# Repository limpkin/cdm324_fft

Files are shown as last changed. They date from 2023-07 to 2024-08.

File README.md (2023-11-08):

# CDM324 v2 FFT Project
This repository contains the source files created for the making of the CDM324 project described on <a href="https://www.limpkin.fr/index.php?post/2022/03/31/CDM324-Doppler-Motion-Sensor-Backpack%2C-now-with-FFTs%21">limpkin.fr</a>  
The assembly may be purchased here: <a href="https://www.tindie.com/products/stephanelec/cdm324-doppler-speed-sensor/">US shop</a> / <a href="https://lectronz.com/products/cdm324-doppler-speed-sensor">EU shop</a>   
<p align="center">
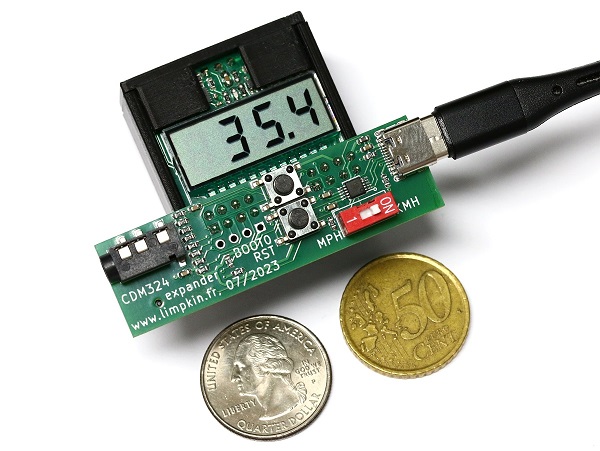
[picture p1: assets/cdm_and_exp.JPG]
CDM324
  
</p>

## Repository Structure
- <b>datasheets</b>: main components datasheets
- <b>fw</b>: firmware source files, used in STM32CubeIDE
- <b>kicad</b>: kicad source files for the "backpack" (cdm324_v2) and the "expansion board" (cdm324_exp)
- <b>scripts</b>: python source files for the tools that are used together with the expansion board

## Quick Interfacing Guide (to be completed)
<p align="center">
  CDM324
</p>

### Unit change to km/h  
To change the speed readout to km/h, connect the "PA1/KMH" pad to the "GND" pad in the above diagram.  

### UART connection  
**The UART connection is 3V3 and NOT 5V.**  
To connect the device to an external platform through UART, please use the MCU UART RX/TX pins shown above.   
The baud rate is **1Mbit/s**, speed **can be queried** by **sending the 'k'** character for km/h or the 'm' character for mph.  
**In case of doubt about the UART connection, reboot the device**: it should output "CDM324 fw....".  
**Make sure your host device can handle 1MBit/s**. If that's not the case, head to the [release section](https://github.com/limpkin/cdm324_fft/releases) to download firmware with different UART baud rates.  
Finally, if you still have doubts about the UART connection, you may connect one of your host platform GPIO to the nRESET pin and reset the CDM324 device at your host platform boot.  

## Reflashing the Device

In the unlikely case you want to reflash your device with another firmware, you may either use the [GUI present in this repository](https://github.com/limpkin/cdm324_fft/tree/main/scripts) or the [stm32loader python module](https://pypi.org/project/stm32loader/) directly :  

> pip install stm32loader
> 
... then with the expansion board connected to the device (**as it uses RTS/CTS signals to control the MCU nRESET and BOOT0 pins**):  

> stm32loader -b 115200 -p  com_port -e -w -v -s -f F3 updatefile.bin

If you don't have the companion expansion board, you may use [STM32 Flash loader](https://www.st.com/en/development-tools/flasher-stm32.html) after performing the following toggling sequence:  
- tie nRESET to GND  
- bring BOOT0 to 3V3_OUT  
- release nRESET  
- releae BOOT0  

## Sample Arduino code to fetch speed from device

```c
#define RESET_PIN 2

void issue_cdm324_reset()
{  
  bool string_received = false;
  char receive_buffer[50];
  int index = 0;

  // 20ms reset
  pinMode(RESET_PIN, OUTPUT);
  delay(20);
  pinMode(RESET_PIN, INPUT);

  // get string
  while (string_received == false)
  {
    if (Serial1.available() > 0)
    {
      char bla = Serial1.read();
      receive_buffer[index++] = bla;
      if (bla == '\n')
        string_received = true;
    }
  }
  receive_buffer[index] = 0;

  Serial.println("Received from the CDM324:");
  Serial.println(receive_buffer);
}

void setup() 
{
  // Local console
  Serial.begin(115200);
  Serial.println("Hello there!");

  // To the CDM324
  Serial1.begin(57600);

  // Reset CDM324
  pinMode(RESET_PIN, INPUT);
  digitalWrite(RESET_PIN, LOW);
  issue_cdm324_reset();
}

float get_speed(bool kmh)
{
  if (kmh == true)
  {
    // Query km/h * 10
    Serial1.print('k');
  }
  else
  {
    // Query mph * 10
    Serial1.print('m');
  }  
  while(Serial1.available() == 0);
  float speed = Serial1.parseFloat();
  return (speed / 10);
}

void loop()
{
  Serial.println(get_speed(false));
  delay(500);
}
```

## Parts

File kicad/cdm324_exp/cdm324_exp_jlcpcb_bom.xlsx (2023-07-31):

Designator | Comment | Footprint | JLCPCB Part #
C1, C2, C3, C4, C5 | 1uF | Capacitor_SMD:C_0603_1608Metric | C1592
FB1 | FerriteBead | Inductor_SMD:L_0603_1608Metric | C14709
J1, J2 | Conn_02x04_Odd_Even | Connector_PinSocket_2.54mm:PinSocket_2x04_P2.54mm_Vertical | C2685133
J3 | USB_C_Receptacle_USB2.0 | Connector_USB:USB_C_Receptacle_G-Switch_GT-USB-7010ASV | C2988369
J5 | Micro_SD_Card_Det1 | lib:XKTF-015-N | C381082
J7 | AudioJack4 | Connector_Audio:Jack_3.5mm_PJ320D_Horizontal | C431535
R1, R4, R5, R6, R7 | 1k | Resistor_SMD:R_0603_1608Metric | C22548
R2, R3 | 5.1k | Resistor_SMD:R_0603_1608Metric | C105580
R8, R9, R10, R11, R12, R13 | 49k9 | Resistor_SMD:R_0603_1608Metric | C114624
SW1, SW2 | SW_Push | Button_Switch_SMD:SW_Push_1P1T_NO_6x6mm_H9.5mm | C255812
SW3 | SW_DIP_x01 | Button_Switch_THT:SW_DIP_SPSTx01_Slide_9.78x4.72mm_W7.62mm_P2.54mm | C126888
U1 | CH340X | Package_SO:MSOP-10_3x3mm_P0.5mm | C3035748

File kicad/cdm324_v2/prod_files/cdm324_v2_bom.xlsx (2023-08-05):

Item # | Qty | Designator | Value | Manufacturer | Manufacturer Part Number | Alternative LCSC part number | Package/Footprint | Digikey Link
1 | 6 | C1, C3, C5, C10, C11, C13 | 22uF | Samsung Electro-Mechanics | CL21A226MOCLRNC | C602037 | 0805 | https://www.digikey.com/product-detail/en/samsung-electro-mechanics/CL21A226MOCLRNC/1276-6780-1-ND/5961639
2 | 1 | C4 | 27pF | YAGEO | CC0603JRNPO9BN270 | C107045 | 0603 | https://www.digikey.com/en/products/detail/yageo/CC0603JRNPO9BN270/302797
3 | 9 | C2, C6, C7, C8, C12, C14, C15, C16, C18 | 470nF | TDK Corporation | C1005X5R1E474K050BB | C92361 | 0402 | https://www.digikey.com/en/products/detail/tdk-corporation/C1005X5R1E474K050BB/2792240
4 | 1 | C9 | 2.2uF | Murata Electronics | GRM188R71A225KE15D | C1607 | 0603 | https://www.digikey.com/en/products/detail/murata-electronics/GRM188R71A225KE15D/1033256
5 | 1 | FB1 | Ferrite_Bead | Laird-Signal Integrity Products | HZ0805D102R-10 | C44838 | 0805 | http://www.digikey.com/product-detail/en/HZ0805D102R-10/240-2397-1-ND/806757
6 | 1 | J2 | Conn_01x03_Female | Sullins Connector Solutions | PPPC031LFBN-RC | C146243 |  | http://www.digikey.com/product-detail/en/sullins-connector-solutions/PPPC031LFBN-RC/S7036-ND/810175
7 | 2 | J4, J5 | Conn_02x04_Odd_Even | Sullins Connector Solutions | PPPC042LFBN-RC | C92271 |  | https://www.digikey.com/en/products/detail/sullins-connector-solutions/PPPC042LFBN-RC/810244
8 | 5 | R1, R4, R8, R9, R10 | 4k7 | YAGEO | RC0603FR-074K7L | C99782 | 0603 | https://www.digikey.com/en/products/detail/yageo/RC0603FR-074K7L/727212
9 | 2 | R2, R7 | 75 | YAGEO | RC0402JR-0775RL | C137841 | 0402 | https://www.digikey.com/en/products/detail/yageo/RC0402JR-0775RL/726505
10 | 2 | R5, R6 | 130k | Panasonic Electronic Components | ERJ-3EKF1303V | C163432 | 0603 | https://www.digikey.com/product-detail/en/panasonic-electronic-components/ERJ-3EKF1303V/P130KHCT-ND/198154
11 | 1 | U1 | LMP7731 | Texas Instruments | LMP7731MF/NOPB | C202252 |  | https://www.digikey.ch/en/products/detail/texas-instruments/LMP7731MF-NOPB/1836050
12 | 1 | U3 | MAX9814 | Analog Devices Inc./Maxim Integrated | MAX9814ETD+T | C41714 |  | https://www.digikey.com/en/products/detail/analog-devices-inc-maxim-integrated/MAX9814ETD-T/1703775
13 | 1 | U4 | NCP163ASN330T1G | onsemi | NCP163ASN330T1G | C603656 |  | https://www.digikey.com/product-detail/en/on-semiconductor/NCP163ASN330T1G/NCP163ASN330T1GOSCT-ND/10233513
14 | 1 | U5 | STM32F301K8Ux | STMicroelectronics | STM32F301K8U6 | C111684 |  | https://www.digikey.com/product-detail/en/stmicroelectronics/STM32F301K8U6/497-17411-ND/5051319
15 | 1 | U6 | PCA8561AHN/AY | NXP USA Inc. | PCA8561AHN/AY | C2653710 |  | https://www.digikey.ch/en/products/detail/nxp-usa-inc/PCA8561AHN-AY/5170024
16 | 1 | U2 | 12PIN TN Positive 4-Digits |  |  |  |  | https://www.aliexpress.com/item/1005003060952508.html
17 | 1 | R3 | 620k | YAGEO | RC0603FR-07620KL | C68737 | 0603

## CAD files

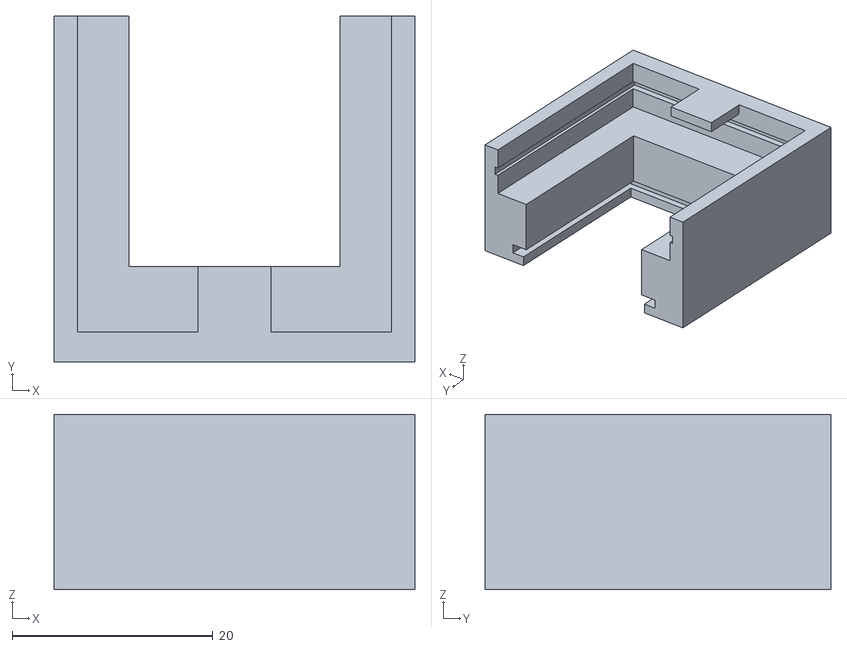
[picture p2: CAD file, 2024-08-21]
holder.stl
36.0 x 34.5 x 17.5

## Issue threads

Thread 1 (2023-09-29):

ffconf.h: No such file or directory

dogualpay, 2023-09-29:
Hi,

I purchased your device and I am trying to extract the .bin file from Cube IDE to upload it with UART connection. However your STM32 Cube IDE project doesn't build. Can you relate ? I couldn't find any proper solution for this issue by searching it on the net.

**Below my console output:**
```
In file included from ../Middlewares/Third_Party/FatFs/src/option/syscall.c:7:
../Middlewares/Third_Party/FatFs/src/option/../ff.h:27:10: fatal error: ffconf.h: No such file or directory
   27 | #include "ffconf.h"  /* FatFs configuration options */
      |          ^~~~~~~~~~
compilation terminated.
In file included from ../Middlewares/Third_Party/FatFs/src/ff_gen_drv.h:38,
                 from ../Middlewares/Third_Party/FatFs/src/diskio.c:40:
../Middlewares/Third_Party/FatFs/src/ff.h:27:10: fatal error: ffconf.h: No such file or directory
   27 | #include "ffconf.h"  /* FatFs configuration options */
      |          ^~~~~~~~~~
compilation terminated.
In file included from ../Middlewares/Third_Party/FatFs/src/ff.c:126:
../Middlewares/Third_Party/FatFs/src/ff.h:27:10: fatal error: ffconf.h: No such file or directory
   27 | #include "ffconf.h"  /* FatFs configuration options */
      |          ^~~~~~~~~~
compilation terminated.
make: *** [Middlewares/Third_Party/FatFs/src/option/subdir.mk:19: Middlewares/Third_Party/FatFs/src/option/syscall.o] Error 1
make: *** Waiting for unfinished jobs....
make: *** [Middlewares/Third_Party/FatFs/src/subdir.mk:25: Middlewares/Third_Party/FatFs/src/diskio.o] Error 1
make: *** [Middlewares/Third_Party/FatFs/src/subdir.mk:25: Middlewares/Third_Party/FatFs/src/ff.o] Error 1
In file included from ../Middlewares/Third_Party/FatFs/src/ff_gen_drv.h:38,
                 from ../Middlewares/Third_Party/FatFs/src/ff_gen_drv.c:29:
../Middlewares/Third_Party/FatFs/src/ff.h:27:10: fatal error: ffconf.h: No such file or directory
   27 | #include "ffconf.h"  /* FatFs configuration options */
      |          ^~~~~~~~~~
compilation terminated.
make: *** [Middlewares/Third_Party/FatFs/src/subdir.mk:25: Middlewares/Third_Party/FatFs/src/ff_gen_drv.o] Error 1
In file included from ../FATFS/App/fatfs.h:26,
                 from ../FATFS/App/fatfs.c:19:
../Middlewares/Third_Party/FatFs/src/ff.h:27:10: fatal error: ffconf.h: No such file or directory
   27 | #include "ffconf.h"  /* FatFs configuration options */
      |          ^~~~~~~~~~
compilation terminated.
make: *** [FATFS/App/subdir.mk:19: FATFS/App/fatfs.o] Error 1
"make -j16 all" terminated with exit code 2. Build might be incomplete.

11:10:57 Build Failed. 11 errors, 0 warnings. (took 962ms)```

limpkin, 2023-09-29:
thanks for flagging this! it seems gitignore was at fault: https://github.com/limpkin/cdm324_fft/commit/985b58a3213550a3e2f7e3fa087a3f2d90b99047

Closed 2023-09-29.

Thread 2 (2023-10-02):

Please share some further infos about this project

will-code-for-pizza, 2023-10-02:
Hi Limpkin.fr

Please provide us beginners with some more infos about the CMD324 FFT:

* Fritzing.org breadboard cabeling example (f.e. for Arduino UNO R4 Wifi)
* Detailed information about the capabilities of onboard connectors shown in [THIS PICTURE](https://www.limpkin.fr/public/cdm324_v2/exp_pinout.png)
* An example Arduino sketch file, that shows, how to print out measured speed on serial console with high accuracy

Many thanks so far.
Have a nice day.

limpkin, 2023-10-03:
Hello,
I'll try to get to it when I have the time.

will-code-for-pizza, 2023-10-03:
Sorry, please don't get me wrong, but you sell your excellent product online without any detailed documentation. It would be nice for every of your customers to follow your developement cabling and Arduino code (which should exist due to your journey of building this backpack V2)

Please upload here and we will find the time to search into it for the needed information for our ongoing projects.

Many thanks.

limpkin, 2023-10-03:
Just to make sure I follow you, are you saying that https://www.limpkin.fr/index.php?post/2022/03/31/CDM324-Doppler-Motion-Sensor-Backpack%2C-now-with-FFTs%21 isn't detailed documentation?

I'm not sure to follow your reasoning: this CDM324 backpack is a **redesign** of its previous version. I therefore don't understand why it should carry its previous version legacy.

In any case, I've updated the readme at https://github.com/limpkin/cdm324_fft to provide basic instructions on how to get the speed through UART. That should hopefully unblock you

will-code-for-pizza, 2023-10-09:
From a developer's perspective, things often seem simple because you had to go through them yourself during the development process, solve the problems and then put the problem aside.

As a customer, you are faced with the challenge of receiving a foreign device with which you have had no contact whatsoever.

I'm trying to illustrate my problem with your documentation (which from your point of view certainly seems extensive and complete) using an example.
The addition to your readme helped me a lot.
Thanks for that!

`
UART connection

To connect the device to an external platform through UART, please use the MCU UART RX/TX pins shown above.
The baud rate is 1Mbit/s, speed can be queried by sending the 'k' character for km/h or the 'm' character for mph.
`

Ok, I understand to connect MCU UART_RX to Arduino Pin 2 (RX) and MCU UART_TX to Arduino Pin 3 (TX).
I have to initialize the UART connection to 1MBit/s with

mySerial.begin(1000000);

and send a "k" (ASCII char 107) to Arduino TX pin.

limpkin, 2023-10-10:
Hello,

- the DOPPLER_OUT isn't part of the UART connection, which is why it is not documented in the UART connection paragraph
- as you're a developer, did you make sure that the Arduino board you're using can actually handle a 1Mbit/s baud rate?

limpkin, 2023-10-10:
> I am using the newest Arduino UNO R4 Wifi, but you are right... It could be that the baud rate is too high for this device.
Could you please provide me with the hardware YOU are using for this ?

I'm not using any hardware, as I've only been using the expansion board

> Would it be possible to use DOPPLER_OUT to calculate the speed with the arduino ?

yes, but that would involve basically doing everything that the on board MCU is already doing.

will-code-for-pizza, 2023-10-10:
> yes, but that would involve basically doing everything that the on board MCU is already doing.

Except the amplification of the signal and accordingly the improved sensitivity of the CDM324, right ?

What would the wiring to an Arduino look like in this case?
Do the signals arrive at the Arduino analog or digital?

Is it also possible to operate the radar module with a different baud rate? (e.g. with 0.5 MBit/s)

Regards.

limpkin, 2023-10-10:
> Except the amplification of the signal and accordingly the improved sensitivity of the CDM324, right ?

the MCU isn't doing any amplification, it's just running an FFT. DOPPLER_OUT is the signal going into the MCU ADC.
You'd therefore have to wire that signal to your board ADC.

As you're a developer, I'm sure you'll be able to recompile these source files to get a new baud rate.

will-code-for-pizza, 2023-10-10:
Hi...

> yes, but that would involve basically doing everything that the on board MCU is already doing.

But I would at least benefit from the signal amplification. Right?
What would the wiring to the Arduino look like in this case?
Are the signals then digital or analog?

Is it also possible to operate the radar module with a different baud rate? (e.g. with 0.5 MBit/s)

Best!

limpkin, 2023-10-10:
> But I would at least benefit from the signal amplification. Right?

correct.

> What would the wiring to the Arduino look like in this case?

connect that signal to your ADC input

> Are the signals then digital or analog?

analog, as extensively described in the website article

> Is it also possible to operate the radar module with a different baud rate? (e.g. with 0.5 MBit/s)

Yes, see my previous answer on that topic.

will-code-for-pizza, 2023-10-10:
Sorry for the double post, my browser (Brave) goes crazy...  :-(   Thanks for the quick response.

will-code-for-pizza, 2023-10-10:
> As you're a developer, I'm sure you'll be able to recompile these source files to get a new baud rate.

No, I am not a developer, I'm a normal person who wants to evaluate a radar signal with an Arduino and display it on a website.
I will try my best.

Maybe that explains all my questions. :-(

will-code-for-pizza, 2023-10-12:
Hi Mathieu, thanks for the hint/link.

I have decided to start from the very beginning and connected your CDM324 to my Raspberry Pi, which can handle up to 3 MBit/s UART.

Cabling:

```
CMD324                  <-->               < -->                 Raspberry Pi
=============================================================================
5V_IN                   external 5V HW-131 5V OUT
GND                     external 5V HW-131 GND
MCU UART_RX                                                      GPIO 15
MCU UART_TX                                                      GPIO 14
```
Reference:
https://www.limpkin.fr/public/cdm324_v2/exp_pinout.png
https://www.elektronik-kompendium.de/sites/raspberry-pi/fotos/raspberry-pi-15b.jpg

(UART connection was tested before on Raspberry Pi (TX/RX direct connection and sending/receiving Strings))

In first terminal:
```
# cat /dev/ttyAMA0
```

In second terminal:
```
Set Baud rate:

# stty -F /dev/ttyAMA0 1000000

Check port setup:

# stty -F /dev/ttyAMA0

Send 'k' to serial:

# echo "k" > /dev/ttyAMA0

or with line feed
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
will-code-for-pizza, 2023-10-17:
Update:

Issue with weird chars solved.  -->  Changed

`char receivedData[ARRAY_SIZE];`

to

`int receivedData[ARRAY_SIZE];`

limpkin, 2023-10-17:
one of my customers is also manually rebooting the CDM324 using the reset input (by driving it low for 100ms)... maybe you could do this too?

will-code-for-pizza, 2023-10-17:
> one of my customers is also manually rebooting the CDM324 using the reset input (by driving it low for 100ms)... maybe you could do this too?

It's not entirely clear to me at the moment how this could help me with my problems.
Oh yes, of course I often switched the module OFF and ON while the UART communication was running in the sketch. Unfortunately without success.

will-code-for-pizza, 2023-10-17:
Oh yes, I almost forgot... Can you please put the two firmwares for 57600 and 1MBit here in the GIT?

limpkin, 2023-10-27:
I've added the bin files to the release tab.

> How do I find the correct baud rate of the RX data so as not to get strange characters?

You should set the baud rate that matches the firmware you've flashed.

> Which string does the module return exactly when sending a 'k' ?

debug_printf("%d\r\n", speed);

> Do I have to/should I send several 'k's to the module to respond?

one char per query

> How to use this method to take multiple measurements per second if the response from the module is (apparently) delayed?

the response won't be delayed

I'm very sorry but there's so much I can help you with without actually digging into your personal code.
I've had several other customers that managed to do what you're trying to do, I'll reach out to them to see if they're willing to share code.

limpkin, 2023-10-29:
sample arduino code has been put on the readme, tested.

will-code-for-pizza, 2023-10-30:
> sample arduino code has been put on the readme, tested.

Thanks for the arduino example
https://github.com/limpkin/cdm324_fft#sample-arduino-code-to-fetch-speed-from-device
but did you realize during your tests, that

- speed is only displayed once, then 0 once and then the output stops ?

```
07:18:11.885 -> Hello there!
07:18:11.917 -> Received from the CDM324:
07:18:11.917 -> CDM324 fw v0.1, compiled Oct  3 2023 16:11:55
07:18:11.917 ->
07:18:11.950 -> 33.90
07:18:13.975 -> 0.00
```

- script crashes in 30% of cases ?

```
07:04:47.190 -> Firmware name: "/tmp/arduino/sketches/3FFDA1E6168788B49E3D5492DF3D250C/sketch_oct30a.ino", compiled on: Oct 30 2023
07:04:47.190 -> Fault on interrupt or bare metal(no OS) environment
07:04:47.222 -> ===== Thread stack information =====
07:04:47.222 ->   addr: 20007ed8    data: 000108b5
07:04:47.222 ->   addr: 20007edc    data: 40046f00
07:04:47.255 ->   addr: 20007ee0    data: 00000000
07:04:47.255 ->   addr: 20007ee4    data: 00009e67
07:04:47.255 ->   addr: 20007ee8    data: 000108b5
07:04:47.287 ->   addr: 20007eec    data: 0000421f
07:04:47.287 ->   addr: 20007ef0    data: 000108b5
07:04:47.287 ->   addr: 20007ef4    data: 000074c3
07:04:47.287 ->   addr: 20007ef8    data: 000074b9
07:04:47.287 ->   addr: 20007efc    data: 00002599
07:04:47.287 -> ====================================
07:04:47.287 -> =================== Registers information ====================
07:04:47.319 ->   R0 : 00000042  R1 : 40070120  R2 : 00000000  R3 : 00000000
07:04:47.319 ->   R12: ffffffff  LR : 000086a1  PC : 00009e00  PSR: 60000000
07:04:47.352 -> ==============================================================
07:04:47.352 -> Usage fault is caused by attempts to switch to an invalid state (e.g., ARM)
07:04:47.385 -> Show more call stack info by run: addr2line -e "/tmp/arduino/sketches/3FFDA1E6168788B49E3D5492DF3D250C/sketch_oct30a.ino".elf -a -f 00009e00 000086a0 00009e66 0000421e 000074c2 000074b8
```
The cause could be that in .arduino15/packages/arduino/hardware/renesas_uno/1.0.4/cores/arduino/Serial.cpp:114

```
  if(init_ok) {
    tx_done = false;
    R_SCI_UART_Write(&uart_ctrl, &c, 1);
    while (!tx_done) {}   //      <<<------ !!!
    return 1;
  }
```
more than one simultaneous access to the serial port should be attempted.
On Arduino, thats not allowed/possible.

At least the one-time output of the speed now works and the documentation is now better when it comes to Arduino.

Thanks a lot and keep grinding!

limpkin, 2023-10-30:
It didn't crash for me, and you'll get 0 when no movement is detected.

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

Closed 2023-10-29.

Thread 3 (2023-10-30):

Issues with sample arduino code

will-code-for-pizza, 2023-10-30:
https://github.com/limpkin/cdm324_fft/issues/2#issuecomment-1784561970

              > sample arduino code has been put on the readme, tested.

Thanks for the arduino example
https://github.com/limpkin/cdm324_fft#sample-arduino-code-to-fetch-speed-from-device
but did you realize during your tests, that

- speed is only displayed once, then 0 once and then the output stops ?

```
07:18:11.885 -> Hello there!
07:18:11.917 -> Received from the CDM324:
07:18:11.917 -> CDM324 fw v0.1, compiled Oct  3 2023 16:11:55
07:18:11.917 ->
07:18:11.950 -> 33.90
07:18:13.975 -> 0.00
```

- script crashes in 30% of cases ?

```
07:04:47.190 -> Firmware name: "/tmp/arduino/sketches/3FFDA1E6168788B49E3D5492DF3D250C/sketch_oct30a.ino", compiled on: Oct 30 2023
07:04:47.190 -> Fault on interrupt or bare metal(no OS) environment
07:04:47.222 -> ===== Thread stack information =====
07:04:47.222 ->   addr: 20007ed8    data: 000108b5
07:04:47.222 ->   addr: 20007edc    data: 40046f00
07:04:47.255 ->   addr: 20007ee0    data: 00000000
07:04:47.255 ->   addr: 20007ee4    data: 00009e67
07:04:47.255 ->   addr: 20007ee8    data: 000108b5
07:04:47.287 ->   addr: 20007eec    data: 0000421f
07:04:47.287 ->   addr: 20007ef0    data: 000108b5
07:04:47.287 ->   addr: 20007ef4    data: 000074c3
07:04:47.287 ->   addr: 20007ef8    data: 000074b9
07:04:47.287 ->   addr: 20007efc    data: 00002599
07:04:47.287 -> ====================================
07:04:47.287 -> =================== Registers information ====================
07:04:47.319 ->   R0 : 00000042  R1 : 40070120  R2 : 00000000  R3 : 00000000
07:04:47.319 ->   R12: ffffffff  LR : 000086a1  PC : 00009e00  PSR: 60000000
07:04:47.352 -> ==============================================================
07:04:47.352 -> Usage fault is caused by attempts to switch to an invalid state (e.g., ARM)
07:04:47.385 -> Show more call stack info by run: addr2line -e "/tmp/arduino/sketches/3FFDA1E6168788B49E3D5492DF3D250C/sketch_oct30a.ino".elf -a -f 00009e00 000086a0 00009e66 0000421e 000074c2 000074b8
```
The cause could be that in .arduino15/packages/arduino/hardware/renesas_uno/1.0.4/cores/arduino/Serial.cpp:114

```
  if(init_ok) {
    tx_done = false;
    R_SCI_UART_Write(&uart_ctrl, &c, 1);
    while (!tx_done) {}   //      <<<------ !!!
    return 1;
  }
```
more than one simultaneous access to the serial port should be attempted.
On Arduino, thats not allowed/possible.

At least the one-time output of the speed now works and the documentation is now better when it comes to Arduino.

Thanks a lot and keep grinding!

_Originally posted by @will-code-for-pizza in https://github.com/limpkin/cdm324_fft/issues/2#issuecomment-1784561970_

limpkin, 2023-10-30:
it does not crash for me at all...
As you have one setup that crashes, perhaps you can contribute to this repository by fixing the issue and issuing a pull request?

will-code-for-pizza, 2023-10-30:
> it does not crash for me at all... As you have one setup that crashes, perhaps you can contribute to this repository by fixing the issue and issuing a pull request?

Of course, I will provide you with a fix, if I have found one.

**First, lets compare hardware and cabling:**

My setup:  Arduino UNO R4 Wifi, CDM324_fft module with LCD and 57600 baud firmware

My cabling:
```
CMD324                  <-->               < -->                 Arduino UNO R4
=============================================================================
nRESET                                                                  PIN 2 digital
5V_IN                   external 5V HW-131 5V OUT
GND                     external 5V HW-131 GND
MCU UART_RX                                                      PIN 1 (TX)
MCU UART_TX                                                      PIN 0 (RX)
```

limpkin, 2023-10-30:
great, looking forward to it!

fluppie, 2023-11-19:
I see the same, flashed the 57600 baud version, send "k" to the terminal (Arduino IDE) and I get one time the speed.
If I press the reset button, I can do it again.

Maybe a continuous sending of the speed to the terminal can also be nice? don't know how many times per second it can send the speed?

limpkin, 2023-12-05:
how's your progress @will-code-for-pizza ?

Closed 2024-02-23.

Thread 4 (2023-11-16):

Trouble installing pyqt5 (Win 10 22H2 with Python 3.7.3)

fluppie, 2023-11-16:
Hi, bought the kit via Lectronz (4158) Any idea why the building is failing? What Python version are you using?
I have python 3.7.3 and pip 23.3 on W10 22H2

```
PS C:\dopplerradar\scripts> pip install pyqt5 chaco stm32loader
Collecting pyqt5
  Using cached PyQt5-5.15.10-cp37-abi3-win_amd64.whl.metadata (2.2 kB)
Requirement already satisfied: chaco in c:\users\philippe\appdata\local\programs\python\python37\lib\site-packages (6.0.0)
Requirement already satisfied: stm32loader in c:\users\philippe\appdata\local\programs\python\python37\lib\site-packages (0.5.1)
Collecting PyQt5-sip<13,>=12.13 (from pyqt5)
  Using cached PyQt5_sip-12.13.0.tar.gz (123 kB)
  Installing build dependencies ... done
  Getting requirements to build wheel ... done
  Preparing metadata (pyproject.toml) ... done
Collecting PyQt5-Qt5>=5.15.2 (from pyqt5)
  Using cached PyQt5_Qt5-5.15.2-py3-none-win_amd64.whl (50.1 MB)
Requirement already satisfied: traits>=6.2.0 in c:\users\philippe\appdata\local\programs\python\python37\lib\site-packages (from chaco) (6.4.3)
Requirement already satisfied: traitsui in c:\users\philippe\appdata\local\programs\python\python37\lib\site-packages (from chaco) (8.0.0)
Requirement already satisfied: pyface>=7.2.0 in c:\users\philippe\appdata\local\programs\python\python37\lib\site-packages (from chaco) (8.0.0)
Requirement already satisfied: numpy in c:\users\philippe\appdata\local\programs\python\python37\lib\site-packages (from chaco) (1.18.2)
Requirement already satisfied: enable>=5.2.0 in c:\users\philippe\appdata\local\programs\python\python37\lib\site-packages (from enable[layout,svg]>=5.2.0->chaco) (6.0.0)
Requirement already satisfied: pyserial in c:\users\philippe\appdata\local\programs\python\python37\lib\site-packages (from stm32loader) (3.4)
Requirement already satisfied: progress in c:\users\philippe\appdata\local\programs\python\python37\lib\site-packages (from stm32loader) (1.6)
Requirement already satisfied: pillow in c:\users\philippe\appdata\local\programs\python\python37\lib\site-packages (from enable>=5.2.0->enable[layout,svg]>=5.2.0->chaco) (9.5.0)
Requirement already satisfied: fonttools in c:\users\philippe\appdata\local\programs\python\python37\lib\site-packages (from enable>=5.2.0->enable[layout,svg]>=5.2.0->chaco) (4.38.0)
Requirement already satisfied: kiwisolver in c:\users\philippe\appdata\local\programs\python\python37\lib\site-packages (from enable[layout,svg]>=5.2.0->chaco) (1.4.5)
Requirement already satisfied: pyparsing in c:\users\philippe\appdata\local\programs\python\python37\lib\site-packages (from enable[layout,svg]>=5.2.0->chaco) (2.4.6)
Requirement already satisfied: importlib-metadata>=3.6 in c:\users\philippe\appdata\local\programs\python\python37\lib\site-packages (from pyface>=7.2.0->chaco) (6.7.0)
Requirement already satisfied: importlib-resources>=1.1.0 in c:\users\philippe\appdata\local\programs\python\python37\lib\site-packages (from pyface>=7.2.0->chaco) (5.12.0)
Requirement already satisfied: zipp>=0.5 in c:\users\philippe\appdata\local\programs\python\python37\lib\site-packages (from importlib-metadata>=3.6->pyface>=7.2.0->chaco) (3.1.0)
Requirement already satisfied: typing-extensions>=3.6.4 in c:\users\philippe\appdata\local\programs\python\python37\lib\site-packages (from importlib-metadata>=3.6->pyface>=7.2.0->chaco) (4.7.1)
Using cached PyQt5-5.15.10-cp37-abi3-win_amd64.whl (6.8 MB)
Building wheels for collected packages: PyQt5-sip
  Building wheel for PyQt5-sip (pyproject.toml) ... error
  error: subprocess-exited-with-error

  × Building wheel for PyQt5-sip (pyproject.toml) did not run successfully.
  │ exit code: 1
  ╰─> [42 lines of output]
      running bdist_wheel
      running build
      running build_ext
      building 'PyQt5.sip' extension
      creating build
      creating build\temp.win-amd64-cpython-37
      creating build\temp.win-amd64-cpython-37\Release
      "C:\Program Files (x86)\Microsoft Visual Studio 14.0\VC\BIN\x86_amd64\cl.exe" /c /nologo /O2 /W3 /GL /DNDEBUG /MD -IC:\Users\Philippe\AppData\Local\Programs\Python\Python37\include -IC:\Users\Philippe\AppData\Local\Programs\Python\Python37\Include "-IC:\Program Files (x86)\Microsoft Visual Studio 14.0\VC\INCLUDE" "-IC:\Program Files (x86)\Microsoft Visual Studio 14.0\VC\ATLMFC\INCLUDE" "-IC:\Program Files (x86)\Windows Kits\10\include\10.0.20348.0\ucrt" "-IC:\Program Files (x86)\Windows Kits\10\include\10.0.20348.0\shared" "-IC:\Program Files (x86)\Windows Kits\10\include\10.0.20348.0\um" "-IC:\Program Files (x86)\Windows Kits\10\include\10.0.20348.0\winrt" /Tcapiversions.c /Fobuild\temp.win-amd64-cpython-37\Release\apiversions.obj
      apiversions.c
      "C:\Program Files (x86)\Microsoft Visual Studio 14.0\VC\BIN\x86_amd64\cl.exe" /c /nologo /O2 /W3 /GL /DNDEBUG /MD -IC:\Users\Philippe\AppData\Local\Programs\Python\Python37\include -IC:\Users\Philippe\AppData\Local\Programs\Python\Python37\Include "-IC:\Program Files (x86)\Microsoft Visual Studio 14.0\VC\INCLUDE" "-IC:\Program Files (x86)\Microsoft Visual Studio 14.0\VC\ATLMFC\INCLUDE" "-IC:\Program Files (x86)\Windows Kits\10\include\10.0.20348.0\ucrt" "-IC:\Program Files (x86)\Windows Kits\10\include\10.0.20348.0\shared" "-IC:\Program Files (x86)\Windows Kits\10\include\10.0.20348.0\um" "-IC:\Program Files (x86)\Windows Kits\10\include\10.0.20348.0\winrt" /EHsc /Tpbool.cpp /Fobuild\temp.win-amd64-cpython-37\Release\bool.obj
      bool.cpp
      "C:\Program Files (x86)\Microsoft Visual Studio 14.0\VC\BIN\x86_amd64\cl.exe" /c /nologo /O2 /W3 /GL /DNDEBUG /MD -IC:\Users\Philippe\AppData\Local\Programs\Python\Python37\include -IC:\Users\Philippe\AppData\Local\Programs\Python\Python37\Include "-IC:\Program Files (x86)\Microsoft Visual Studio 14.0\VC\INCLUDE" "-IC:\Program Files (x86)\Microsoft Visual Studio 14.0\VC\ATLMFC\INCLUDE" "-IC:\Program Files (x86)\Windows Kits\10\include\10.0.20348.0\ucrt" "-IC:\Program Files (x86)\Windows Kits\10\include\10.0.20348.0\shared" "-IC:\Program Files (x86)\Windows Kits\10\include\10.0.20348.0\um" "-IC:\Program Files (x86)\Windows Kits\10\include\10.0.20348.0\winrt" /EHsc /Tcdescriptors.c /Fobuild\temp.win-amd64-cpython-37\Release\descriptors.obj
      descriptors.c
      "C:\Program Files (x86)\Microsoft Visual Studio 14.0\VC\BIN\x86_amd64\cl.exe" /c /nologo /O2 /W3 /GL /DNDEBUG /MD -IC:\Users\Philippe\AppData\Local\Programs\Python\Python37\include -IC:\Users\Philippe\AppData\Local\Programs\Python\Python37\Include "-IC:\Program Files (x86)\Microsoft Visual Studio 14.0\VC\INCLUDE" "-IC:\Program Files (x86)\Microsoft Visual Studio 14.0\VC\ATLMFC\INCLUDE" "-IC:\Program Files (x86)\Windows Kits\10\include\10.0.20348.0\ucrt" "-IC:\Program Files (x86)\Windows Kits\10\include\10.0.20348.0\shared" "-IC:\Program Files (x86)\Windows Kits\10\include\10.0.20348.0\um" "-IC:\Program Files (x86)\Windows Kits\10\include\10.0.20348.0\winrt" /EHsc /Tcint_convertors.c /Fobuild\temp.win-amd64-cpython-37\Release\int_convertors.obj
      int_convertors.c
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
limpkin, 2023-11-18:
well it does look like the program tries to open the port... it looks like something else now.
maybe try these suggestions? https://stackoverflow.com/questions/20879939/pyserial-error-cannot-open-port

fluppie, 2023-11-18:
This simple code does not return any errors
```

import serial

serialPort = serial.Serial(port = "COM2", baudrate=1000000,
                           bytesize=8, timeout=2, stopbits=serial.STOPBITS_ONE)

serialPort.close()
```

Testing the code on the other COM ports in my system does return some errors now and then.
```

PS C:\dopplerradar\scripts> py comtestcloseCOM2.py
PS C:\dopplerradar\scripts> py comtestcloseCOM3.py
Traceback (most recent call last):
  File "C:\dopplerradar\scripts\comtestcloseCOM3.py", line 3, in <module>
    serialPort = serial.Serial(port = "COM3", baudrate=1000000,
                 ^^^^^^^^^^^^^^^^^^^^^^^^^^^^^^^^^^^^^^^^^^^^^^
  File "C:\Python311\Lib\site-packages\serial\serialwin32.py", line 33, in __init__
    super(Serial, self).__init__(*args, **kwargs)
  File "C:\Python311\Lib\site-packages\serial\serialutil.py", line 244, in __init__
    self.open()
  File "C:\Python311\Lib\site-packages\serial\serialwin32.py", line 80, in open
    self._reconfigure_port()
  File "C:\Python311\Lib\site-packages\serial\serialwin32.py", line 222, in _reconfigure_port
    raise SerialException(
serial.serialutil.SerialException: Cannot configure port, something went wrong. Original message: OSError(22, 'De parameter is onjuist.', None, 87)
PS C:\dopplerradar\scripts> py comtestcloseCOM4.py
Traceback (most recent call last):
  File "C:\dopplerradar\scripts\comtestcloseCOM4.py", line 3, in <module>
    serialPort = serial.Serial(port = "COM4", baudrate=1000000,
                 ^^^^^^^^^^^^^^^^^^^^^^^^^^^^^^^^^^^^^^^^^^^^^^
  File "C:\Python311\Lib\site-packages\serial\serialwin32.py", line 33, in __init__
    super(Serial, self).__init__(*args, **kwargs)
  File "C:\Python311\Lib\site-packages\serial\serialutil.py", line 244, in __init__
    self.open()
  File "C:\Python311\Lib\site-packages\serial\serialwin32.py", line 64, in open
    raise SerialException("could not open port {!r}: {!r}".format(self.portstr, ctypes.WinError()))
serial.serialutil.SerialException: could not open port 'COM4': OSError(22, 'De time-outperiode van de semafoor is verlopen.', None, 121)
PS C:\dopplerradar\scripts> py comtestcloseCOM5.py
PS C:\dopplerradar\scripts>
```

I then tried to change line 25 in _start.py to:
`		ports = ['COM%s' % (i + 1) for i in range(7,256)]`
So the first COM port it can find is COM8, changed the CH340 from COM2 to COM8 and voila, tiny step further:
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

Now we need to know why it cannot open the com port. Is there a way to force the script to use COM8 and not do any com port scan?

limpkin, 2023-11-18:
I'm afraid not, as your error happens when python tries to talk with COM2: https://github.com/limpkin/cdm324_fft/blob/main/scripts/_start.py#L133
at this line, could you add a print(com_port) ? it should report COM2.
worst case, could you add here: https://github.com/limpkin/cdm324_fft/blob/main/scripts/_start.py#L133 the following line: return ["COM2"]

fluppie, 2023-11-19:
Because of line 25 https://github.com/limpkin/cdm324_fft/blob/main/scripts/_start.py#L25
ports = ['COM%s' % (i + 1) for i in range(2,256)]
COM3 is the earliest com port that can be found, so that's why I changed the com port in the W10 device manager from com2 to com 8 and changed the detection range to (5,256).

Now it finds COM8 (this is correct, the cdm324 device) and that gives me this:
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

limpkin, 2023-11-19:
no button needs to be pressed indeed.
just to make sure the serial link is working, could you try the reflashing procedure ( https://github.com/limpkin/cdm324_fft#reflashing-the-device ) with https://github.com/limpkin/cdm324_fft/releases/download/v1.00/cdm324_1000000.bin ?

fluppie, 2023-11-19:
I can also make the debug tool work when hardcoding the com port
```
		# Launch debug tool
		self.com_port = "COM8"
		stream_vis_start(self.com_port)
```

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

But I need to reset the device to re-run the script after closing the window. Probably because the com_port isn't closed properly with this hardcoded COM8.
```
PS C:\dopplerradar\scripts> python _start.py
COM8
2023-11-19 21:10:17.086388: skipping one frame
2023-11-19 21:10:26.237943: skipping one frame
2023-11-19 21:10:26.407199: skipping one frame
2023-11-19 21:10:26.718888: skipping one frame
2023-11-19 21:10:28.005532: skipping one frame
2023-11-19
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

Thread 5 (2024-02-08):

dopplersensor display stuck at 0.4

Marcus-Peterson, 2024-02-08:
So, I have a voltage divider the delivers electricity to the dopplersensor, whenever I connect the 5v and GND to the mb102, the display shifts between a bunch of numbers (if I wave my hand in front of it for example). And after a couple of seconds it's stuck at 0.4, and sometimes all I can see is a segment go around in circles.

I've tested to see if there was something wrong with the doppler sensor through the expansion board and connected it via usbc to my pc, but nothing. It seems fine..? It detects speeds flawlessly.

When a/the segment goes around in circles it is incapable of detecting movements

What is going on here?

limpkin, 2024-02-08:
hello,
Can you expand on " I have a voltage divider the delivers electricity to the dopplersensor"?
Is that the mb102 you're referring to? https://www.az-delivery.de/en/products/mb102-breadboard
could you send a picture of your wiring diagram?

will-code-for-pizza, 2024-03-18:
I have a similar issue:

If I connect the CDM324 "standalone" via expansion board to USB 5V, measuring speed works fine.
Module detects movements and if nothing happened, the display shows circling line.

If I connect CDM324 to Arduino

```
CMD324   <----->   Arduino UNO R4 Wifi
=================================
nRESET             PIN 2 digital
5V_IN              5V (do NOT use external power supply or script will crash!)
GND                GND
MCU UART_RX        PIN 1 (TX)
MCU UART_TX        PIN 0 (RX)
```

display shows a constant speed ~ 4 km/h (range from 3.80 to 4.20 km/h)

will-code-for-pizza, 2024-03-18:
Additional video from issue:

https://youtube.com/shorts/JUVHfLQQhDU

limpkin, 2024-03-18:
@will-code-for-pizza your issue seems to be related to a noisy power supply, possibly injecting noise into the CDM324

will-code-for-pizza, 2024-03-19:
> @will-code-for-pizza your issue seems to be related to a noisy power supply, possibly injecting noise into the CDM324

I shouldn't have bought that Chinese junk... (the power supply)    :-(

Closed 2024-03-25.

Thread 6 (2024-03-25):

UART and 'k','u' commands & streaming data from CDM 324

Marcus-Peterson, 2024-03-25:
Quick question:
When I send the 'k' to the doppler radar from let's say an MCU. Does my MCU only have to send it once and the data can be "streamed" or does the MCU need to send the 'k' command to get a new speed reading every time?

limpkin, 2024-03-25:
the latter :)

Marcus-Peterson, 2024-03-26:
Okay thanks. The reason I asked is because I can't seem to figure out how to actually stream data to my arduino:
`#include <Arduino.h>
#include <MKRWAN_v2.h>
#include <ArduinoJson.h>
#include "mkrwan_doppler_v3.h"

#define BUFFER_SIZE 64

uint8_t buffer[BUFFER_SIZE];
unsigned int bufferIndex = 0;
char command = UART_COMMAND; // 'k' for km/h, 'm' for mph

const String appEui = APP_EUI;
const String appKey = APP_KEY;
LoRaModem modem;

float realSpeedValue = -1.0; // Initialize to -1 to indicate no valid data yet

bool commandSent = false; // Added flag to track if the command has been sent

void setup() {
  Serial.begin(115200);
  while (!Serial);
  Serial1.begin(1000000);

  if (!modem.begin(EU868)) {
    Serial.println("Failed to start module");
    return;
  }

  Serial.println("Connecting via OTAA...");
  if (!modem.joinOTAA(appEui, appKey)) {
    Serial.println("OTAA connection failed");
    return;
  }
  Serial.println("OTAA successfully connected");
  sendCommandToRadar(); // This will send the initial command
}

void loop() {
  readRadarData();
  if (realSpeedValue > 0) {  // Check for positive, valid data
    sendLoRaMessage();
  }
}

void sendCommandToRadar() {
  if (!commandSent) {
    Serial1.write(command);
    Serial.println(String("Command '") + command + "' sent to radar.");
    commandSent = true;
  }
}

void processData() {
  if (bufferIndex < 1) return;

  char receivedString[BUFFER_SIZE + 1];
  strncpy(receivedString, (char*)buffer, bufferIndex);
  receivedString[bufferIndex] = '\0';
  Serial.print("Raw data received from radar: ");
  Serial.println(receivedString);

  if (isDigit(receivedString[0]) || receivedString[0] == '-') {
    float speedValue = atof(receivedString);
    if (speedValue > 0.0) {
      realSpeedValue = speedValue / 10.0;
      Serial.print("Interpreted speed value: ");
      Serial.println(realSpeedValue);
    }
  }
}

String JsonProcessor(float arg) {
  if (arg > 0.0) {
    StaticJsonDocument<200> doc;
    doc["kmh"] = arg;
    String output;
    serializeJson(doc, output);
    return output;
  }
  return "";
}

void readRadarData() {
  while (Serial1.available()) {
    buffer[bufferIndex++] = Serial1.read();
    if (bufferIndex == BUFFER_SIZE || !Serial1.available()) {
      processData();
      bufferIndex = 0; // Återställer bufferIndex för nästa läsning
    }
  }
}

void sendLoRaMessage() {
  static unsigned long lastSendTime = 0;
  if (millis() - lastSendTime > 10000 && realSpeedValue > 0.001) {
    String jsonData = JsonProcessor(realSpeedValue);
    if (!jsonData.isEmpty()) {
      modem.setPort(3);
      modem.beginPacket();
      modem.print(jsonData);
      int packetSuccess = modem.endPacket(true);
      if (packetSuccess > 0) {
        Serial.println("Message sent correctly: " + jsonData);
      } else {
        Serial.println("Error sending message! Error code: " + String(packetSuccess));
      }
      realSpeedValue = -1.0; // Möjliggör ny datauppdatering
    }
    lastSendTime = millis();
  }
}
`

Marcus-Peterson, 2024-03-26:
So just to be clear, I'll have to send a new command (the 'k') to the radar everytime I want to get a speed reading?

limpkin, 2024-03-26:
that's correct :)

Marcus-Peterson, 2024-04-22:
@limpkin
I understand that this issue is closed, but I believe it's better to continue the discussion here instead of opening a new issue for the same topic. Apologies if I'm repeating myself, but I want to ensure that I have a clear understanding of the communication process with the CDM 324.

As I understand it, the data from the CDM 324 cannot be continuously streamed to a device, such as a serial monitor. Instead, to obtain new speed-data values, the MCU must send a 'k' command each time it wants to read a new value. Could you confirm whether my understanding is correct?

For example, if I send the 'k' command once from the MCU, can I then set up some programmatic logic in, let's say an MCU and start a continuous streaming of speed-data values to a serial monitor? Or does each new data value require sending the command again, every time I want a new speed-data value? I ask because many applications using UART communication can continuously stream data. I'm a little confused trying to determine if this applies to the CDM 324 or if my current understanding of the way an MCU for example need to do, in order for it to collect a speed-data value (Ergo, it needs to send the 'k' command over and over to obtain new speed-data).

To clarify my question, here's a Python script demonstrating what I mean by data streaming over UART. Although I haven't tested this script, it should illustrate the concept:

```
import serial

# Set up UART communication parameters
uart = serial.Serial(port='/dev/ttyS1', baudrate=9600, bytesize=serial.EIGHTBITS, parity=serial.PARITY_NONE, stopbits=serial.STOPBITS_ONE)

# Transmit a data stream (example: sending a string continuously)
data = "Hello, UART streaming!"
uart.write(data.encode())  # Transmit data as bytes

# Receive a data stream (example: reading a buffer of 100 bytes)
received_data = uart.read(100)  # Read 100 bytes from UART

```

Can you confirm if the CDM 324 behaves like this, where it allows continuous streaming, or if each new data retrieval requires sending a new command? Your guidance would be greatly appreciated.

Marcus-Peterson, 2024-04-22:
Also, How do I reopen issue? There is not button

limpkin, 2024-04-22:
> such as a serial monitor. Instead, to obtain new speed-data values, the MCU must send a 'k' command each time it wants to read a new value. Could you confirm whether my understanding is correct?

that is correct indeed :)

> Or does each new data value require sending the command again, every time I want a new speed-data value

that indeed

> Can you confirm if the CDM 324 behaves like this, where it allows continuous streaming, or if each new data retrieval requires sending a new command?

the latter

Tell you what, whenever I have time i'll try to code a streaming mode :)

henridbr, 2024-04-22:
So I am not alone. This question seems obvious but it's not.
My first idea was that the sensor is sending a flow of data but it's not the case.
The sensor answers only when "k" is sent like the cop's handheld radar when he pushes on the  trigger.
It is possible to add a presence detector (with an acute angle of detection) to do that.
Or by software to send "k" continuously in order to receive a flow of values and filter them to get useful data.
Many problems I guess to discriminate different objects.

Marcus-Peterson, 2024-04-23:
> So I am not alone. This question seems obvious, but it's not. My first idea was that the sensor is sending a flow of data because the screen is always showing speed, but it's not the case. The sensor answers only when "k" is sent like the cop's handheld radar when he pushes on the trigger. It is possible to add a presence detector (with an acute angle of detection) to do that. Or by software to send "k" continuously in order to receive a flow of values and filter them to get useful data. Many problems I guess to discriminate different objects.

Yes indeed, the only way I got, what you could consider a "stream" (It's not an actual stream, but it kind of looks like one). Is to just send a command to the radar every 600 milliseconds.
But the problem with that is that it can cause problems later down the line once you want to say for example do counting and stuff like that.

But yeah, I am less confused hope you are as well.

Unless someone has any other thoughts or ideas, we can most likely close down this issue, again.

Marcus-Peterson, 2024-04-23:
And also @limpkin I want to thank you personally for taking your time and answering all of the community's question. I appreciate this a lot. And I'm very grateful.

I'll make sure to contribute what I can to this FOS project. to make it easier for you.

limpkin, 2024-04-23:
sure! let me know if you have any other question :)

Closed 2024-04-23.

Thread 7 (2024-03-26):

How to get UART stream to Arduino

Marcus-Peterson, 2024-03-26:
Okay, so I have this Arduino code here for the MKRWAN. The problem I am encountering is that I don't know how to actually set up a data stream to my Arduino.

```
#include <MKRWAN_v2.h>
#include <ArduinoJson.h>
#include "mkrwan_doppler_v3.h"

#define BUFFER_SIZE 64

uint8_t buffer[BUFFER_SIZE];
unsigned int bufferIndex = 0;
char command = UART_COMMAND; // 'k' for km/h, 'm' for mph

const String appEui = APP_EUI;
const String appKey = APP_KEY;
LoRaModem modem;

float realSpeedValue = -1.0; // Initialize to -1 to indicate no valid data yet

bool commandSent = false; // Added flag to track if the command has been sent

void setup() {
  Serial.begin(115200);
  while (!Serial);
  Serial1.begin(1000000);

  if (!modem.begin(EU868)) {
    Serial.println("Failed to start module");
    return;
  }

  Serial.println("Connecting via OTAA...");
  if (!modem.joinOTAA(appEui, appKey)) {
    Serial.println("OTAA connection failed");
    return;
  }
  Serial.println("OTAA successfully connected");
  sendCommandToRadar(); // This will send the initial command
}

void loop() {
  readRadarData();
  if (realSpeedValue > 0) {  // Check for positive, valid data
    sendLoRaMessage();
  }
}

void sendCommandToRadar() {
  if (!commandSent) {
    Serial1.write(command);
    Serial.println(String("Command '") + command + "' sent to radar.");
    commandSent = true;
  }
}

void processData() {
  if (bufferIndex < 1) return;

  char receivedString[BUFFER_SIZE + 1];
  strncpy(receivedString, (char*)buffer, bufferIndex);
  receivedString[bufferIndex] = '\0';
  Serial.print("Raw data received from radar: ");
  Serial.println(receivedString);

  if (isDigit(receivedString[0]) || receivedString[0] == '-') {
    float speedValue = atof(receivedString);
    if (speedValue > 0.0) {
      realSpeedValue = speedValue / 10.0;
      Serial.print("Interpreted speed value: ");
      Serial.println(realSpeedValue);
    }
  }
}

String JsonProcessor(float arg) {
  if (arg > 0.0) {
    StaticJsonDocument<200> doc;
    doc["kmh"] = arg;
    String output;
    serializeJson(doc, output);
    return output;
  }
  return "";
}

void readRadarData() {
  while (Serial1.available()) {
    buffer[bufferIndex++] = Serial1.read();
    if (bufferIndex == BUFFER_SIZE || !Serial1.available()) {
      processData();
      bufferIndex = 0; // Återställer bufferIndex för nästa läsning
    }
  }
}

void sendLoRaMessage() {
  static unsigned long lastSendTime = 0;
  if (millis() - lastSendTime > 10000 && realSpeedValue > 0.001) {
    String jsonData = JsonProcessor(realSpeedValue);
    if (!jsonData.isEmpty()) {
      modem.setPort(3);
      modem.beginPacket();
      modem.print(jsonData);
      int packetSuccess = modem.endPacket(true);
      if (packetSuccess > 0) {
        Serial.println("Message sent correctly: " + jsonData);
      } else {
        Serial.println("Error sending message! Error code: " + String(packetSuccess));
      }
      realSpeedValue = -1.0; // Möjliggör ny datauppdatering
    }
    lastSendTime = millis();
  }
}
```

In the first iteration of the code, I simply send the 'k' command once every set interval (The interval was arbitrary, it could be changed to 10000 milliseconds or 1000 milliseconds, or any milliseconds for that matter)

Marcus-Peterson, 2024-03-26:
yeah, sorry for this. I did read the first issue I posted here wrong.

Closed 2024-03-26.

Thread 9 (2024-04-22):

CDM324 Monitoring Tool does not connect

henridbr, 2024-04-22:
Hi,

Using the bootloader I was able to change the baud rate to 57600.

At first I replaced the baud rate of 1000000 by 57600 in the scripts:

-  stream_visualizer.py (lines 253-254)
-  cdm324_device.py (lines 29-30).

I connected the expansion board to my computer by USB, it's on COM8 set at 57600 bauds.

Then : `python "C:\Users\henri\...\cdm324_fft-main\scripts\_start.py" `
and I got the CDM324 Monitoring Tool.

Unfortunately it did not connect. The port field changed alternatively from COM4 to COM8 with the background color in white, but nothing occurs.
When I disconnected the USB cable, the backcolor of the COM field became red with the warning "No COM ports detected!"

Pushing the Debug button, I got some information:

> PS C:\Users\henri> python "C:\Users\henri\...\cdm324_fft-main\scripts\_start.py"
Exception in Tkinter callback
Traceback (most recent call last):
  File "C:\Program Files\WindowsApps\PythonSoftwareFoundation.Python.3.12_3.12.1008.0_x64__qbz5n2kfra8p0\Lib\tkinter\__init__.py", line 1967, in __call__
    return self.func(*args)
           ^^^^^^^^^^^^^^^^
  File "C:\Users\henri\...\cdm324_fft-main\scripts\_start.py", line 226, in <lambda>
    self.update_fw_button = tk.Button(self, text="Start Debug Tool", font=tkfont.Font(family='Helvetica', size=9), width="18", command=lambda:[self.start_debug_tool()])
                                                                                                                                               ^^^^^^^^^^^^^^^^^^^^^^^
  File "C:\Users\henri\...\cdm324_fft-main\scripts\_start.py", line 98, in start_debug_tool
    stream_vis_start(self.com_port)
  File "C:\Users\henri\...\cdm324_fft-main\scripts\stream_visualizer.py", line 253, in stream_vis_start
    platform_serial = serial.Serial(com_port, 57600)
                      ^^^^^^^^^^^^^^^^^^^^^^^^^^^^^^
  File "C:\Users\henri\AppData\Local\Packages\PythonSoftwareFoundation.Python.3.12_qbz5n2kfra8p0\LocalCache\local-packages\Python312\site-packages\serial\serialwin32.py", line 33, in __init__
    super(Serial, self).__init__(*args, **kwargs)
  File "C:\Users\henri\AppData\Local\Packages\PythonSoftwareFoundation.Python.3.12_qbz5n2kfra8p0\LocalCache\local-packages\Python312\site-packages\serial\serialutil.py", line 244, in __init__
    self.open()
  File "C:\Users\henri\AppData\Local\Packages\PythonSoftwareFoundation.Python.3.12_qbz5n2kfra8p0\LocalCache\local-packages\Python312\site-packages\serial\serialwin32.py", line 64, in open
    raise SerialException("could not open port {!r}: {!r}".format(self.portstr, ctypes.WinError()))
serial.serialutil.SerialException: could not open port '': FileNotFoundError(2, 'Le chemin d’accès spécifié est introuvable.', None, 3)
Exception in Tkinter callback
Traceback (most recent call last):
  File "C:\Program Files\WindowsApps\PythonSoftwareFoundation.Python.3.12_3.12.1008.0_x64__qbz5n2kfra8p0\Lib\tkinter\__init__.py", line 1967, in __call__
    return self.func(*args)
           ^^^^^^^^^^^^^^^^
  File "C:\Users\henri\...\cdm324_fft-main\scripts\_start.py", line 226, in <lambda>
    self.update_fw_button = tk.Button(self, text="Start Debug Tool", font=tkfont.Font(family='Helvetica', size=9), width="18", command=lambda:[self.start_debug_tool()])
                                                                                                                                               ^^^^^^^^^^^^^^^^^^^^^^^
  File "C:\Users\henri\...\cdm324_fft-main\scripts\_start.py", line 98, in start_debug_tool
    stream_vis_start(self.com_port)
  File "C:\Users\henri\...\cdm324_fft-main\scripts\stream_visualizer.py", line 253, in stream_vis_start
    platform_serial = serial.Serial(com_port, 57600)
                      ^^^^^^^^^^^^^^^^^^^^^^^^^^^^^^
  File "C:\Users\henri\AppData\Local\Packages\PythonSoftwareFoundation.Python.3.12_qbz5n2kfra8p0\LocalCache\local-packages\Python312\site-packages\serial\serialwin32.py", line 33, in __init__
    super(Serial, self).__init__(*args, **kwargs)
  File "C:\Users\henri\AppData\Local\Packages\PythonSoftwareFoundation.Python.3.12_qbz5n2kfra8p0\LocalCache\local-packages\Python312\site-packages\serial\serialutil.py", line 244, in __init__
    self.open()
  File "C:\Users\henri\AppData\Local\Packages\PythonSoftwareFoundation.Python.3.12_qbz5n2kfra8p0\LocalCache\local-packages\Python312\site-packages\serial\serialwin32.py", line 64, in open
    raise SerialException("could not open port {!r}: {!r}".format(self.portstr, ctypes.WinError()))
serial.serialutil.SerialException: could not open port '': FileNotFoundError(2, 'Le chemin d’accès spécifié est introuvable.', None, 3)
>

Marcus-Peterson, 2024-04-23:
Could you share your code here so that we can help?

limpkin, 2024-04-23:
the rx_size & tx_size value shouldn't be changed (they are buffer size values). Only the serial.Serial() value should be changed.
Can you confirm that a standard terminal program allows you to talk to the platform?

henridbr, 2024-04-24:
I tried both buffer sizes, same result with the GUI and debug.
Connected by USB to the expansion board with the port set at 57600 bauds, I receive the boot message (reset button) and some speed values but not each time I send "k".
It works fine with the FTDI232.

limpkin, 2024-04-24:
So I just re-tried on my end flashing the 57600 firmware (with the _start.py script), modifying line 29 of _start.py to change '1000000' with '57600' and managed to get the GUI (not debug tool) running.
Please note that the debug tool will NOT work with a 57600 firmware as the baud rate will simply limit what's possible to broadcast.

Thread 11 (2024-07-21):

Incorrect idle speed when querying UART

thomergil, 2024-07-21:
With the UART disconnected all is working great. When querying the UART (e.g., the example code in the README) it returns 58 mph when idling. (It shows the correct speed when there's an object.)

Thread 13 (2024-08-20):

STL or 3d print file for the printed case that holds the CDM324 and its backpack.

HAV0X1014, 2024-08-20:
I've looked around this repo and the other CDM324 backpack repo, and cannot find the specific STL file that the CDM324 radar listing on Tindie uses. I'd like this specific version as it appears to be stronger/thicker than the STL provided on the CDM324 backpack repo, actually fits the LCD and PCB used, and I'd like to see if I can add a cone onto the end to direct the "view" of the radar better. I'd also like it just because it looks nicer :)

Thank you for all of your work!

limpkin, 2024-08-21:
oh I had forgotten about uploading it... thanks for reminding me :)

Closed 2024-08-21.

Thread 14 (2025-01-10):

correct schematic version

petit-miner, 2025-01-10:
Hi there,
thanks a lot for your work! The schematic of the analog part uploaded here is different than in your blog post.
Could you tell me which version is better?
If I use C2 with 470nF and R1 with 4k7 and R3 with 130k and C4 with 200pF I get less noise on the input. So should I roll with that?
Thanks a lot!

limpkin, 2025-01-11:
you should indeed roll with this :). C2 with 470nF is a higher high pass filter

Closed 2025-01-11.

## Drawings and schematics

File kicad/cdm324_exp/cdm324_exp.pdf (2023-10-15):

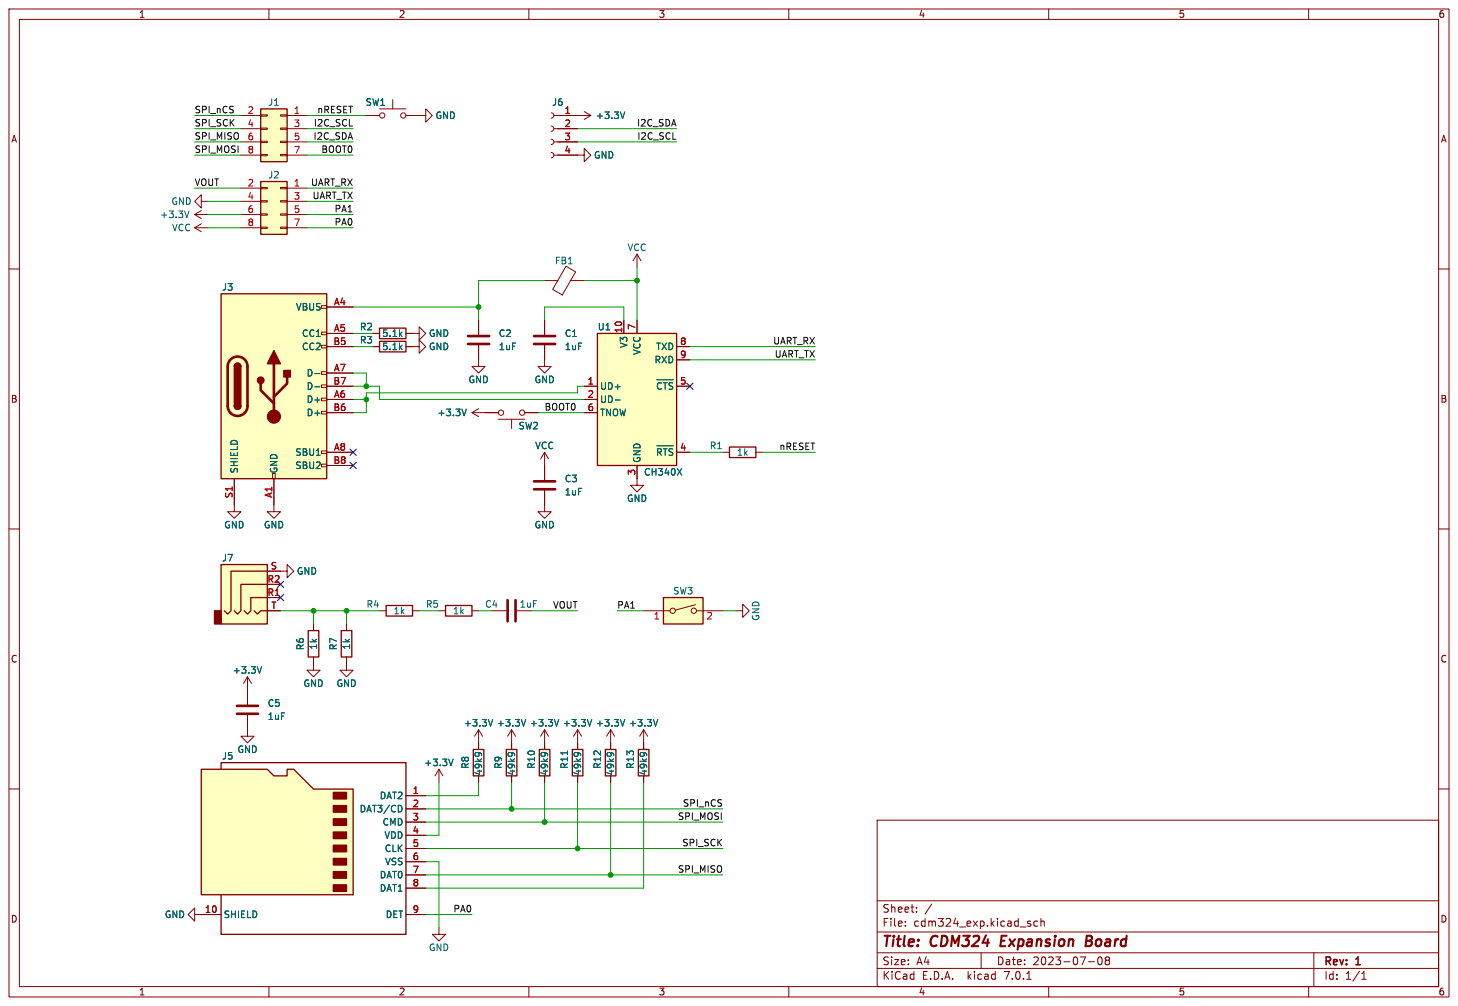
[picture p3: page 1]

3 ~{RTS}4 ~{CTS}5 TNOW 6 VCC

Id: 1/1 Title: CDM324 Expansion Board

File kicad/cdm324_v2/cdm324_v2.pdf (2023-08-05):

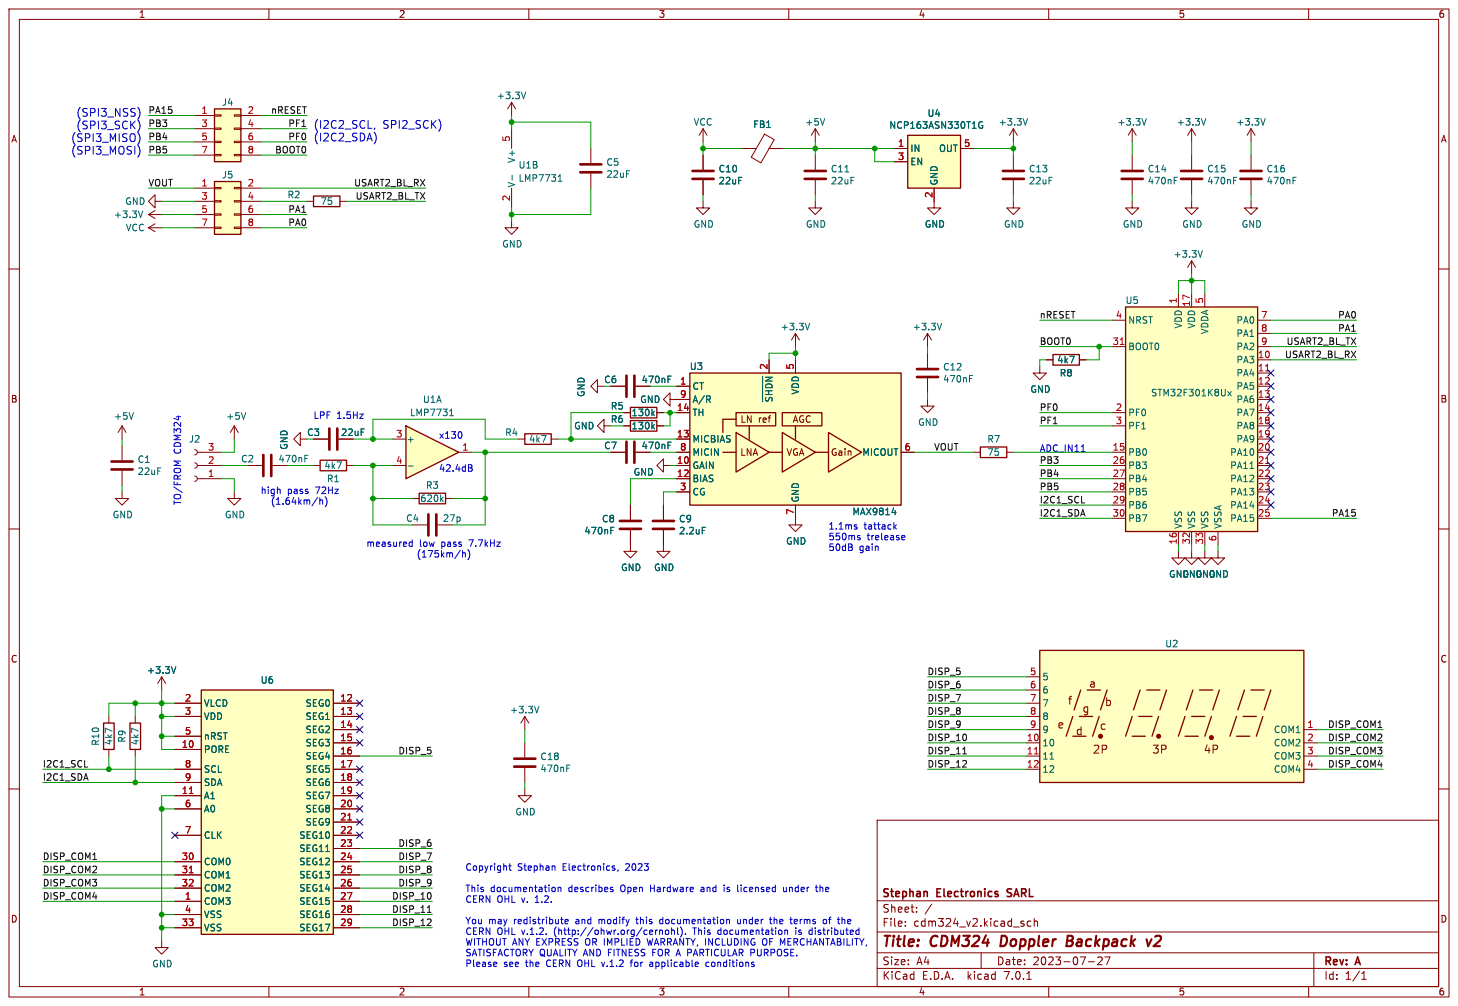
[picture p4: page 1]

2 EN 3 OUT 5 U3 MAX9814 CT 1 GAIN 10 BIAS 12 MICBIAS 13 TH 14 ~{SHDN}2 CG 3 VDD

1 PA3 10 PA4 11 PA5 12 PA6 13 PA7 14 PB0 15 VSS 16 VDD 17 PA8 18 PA9 19 PF0 2 PA10 20 PA11 21 PA12 22 PA13 23 PA14 24 PA15 25 PB3 26 PB4 27 PB5 28 PB6 29 PF1 3 PB7 30 BOOT0 31 VSS 32 VSS 33 NRST 4 VDDA

Id: 1/1 Title: CDM324 Doppler Backpack v2

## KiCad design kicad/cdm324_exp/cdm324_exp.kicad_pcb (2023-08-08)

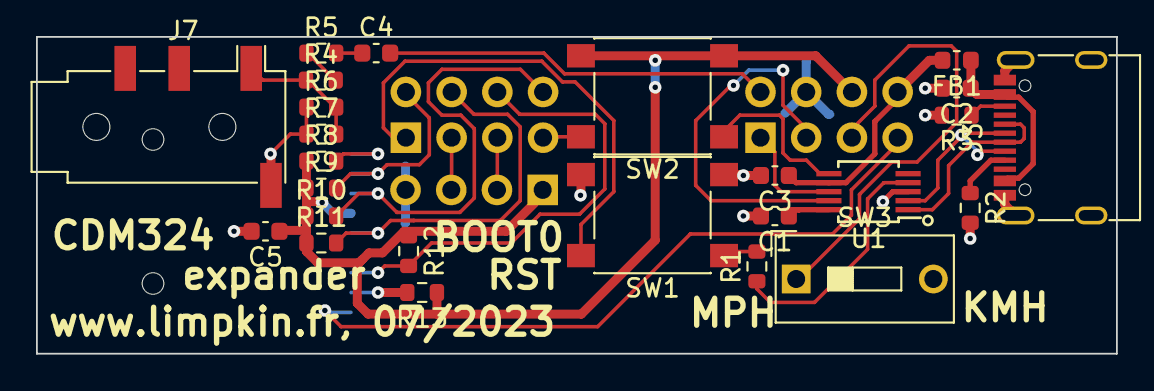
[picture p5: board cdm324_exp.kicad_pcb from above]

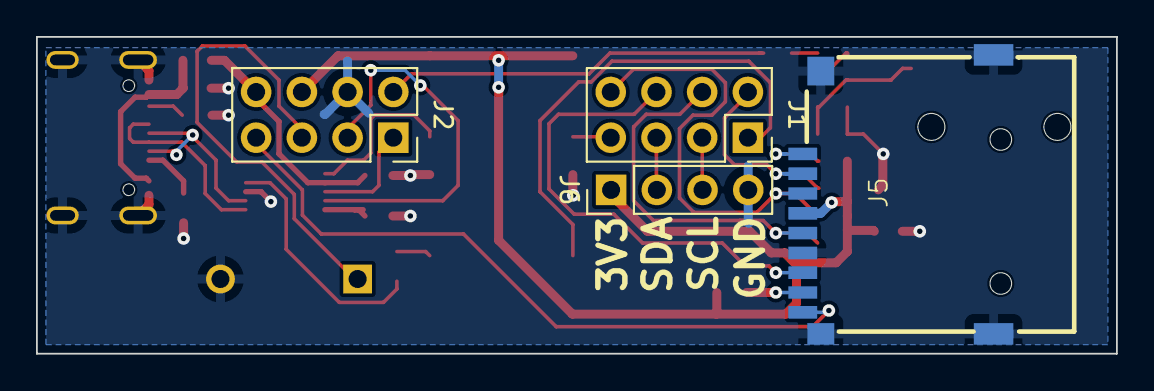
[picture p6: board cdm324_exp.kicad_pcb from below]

Board: 2 copper layers, 60.0 x 17.6 mm, 29 parts (4 on the bottom side), 28 nets.

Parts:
C1, C2, C3, C4, C5: 1uF; C_0603_1608Metric
FB1: FerriteBead; L_0603_1608Metric
J1, J2: Conn_02x04_Odd_Even; PinSocket_2x04_P2.54mm_Vertical
J3: USB_C_Receptacle_USB2.0; USB_C_Receptacle_G-Switch_GT-USB-7010ASV
J5: Micro_SD_Card_Det1; XKTF-015-N
J6: Conn_01x04_Socket; PinHeader_1x04_P2.54mm_Vertical
J7: AudioJack4; Jack_3.5mm_PJ320D_Horizontal
R1, R4, R5, R6, R7: 1k; R_0603_1608Metric
R2, R3: 5.1k; R_0603_1608Metric
R8, R9, R10, R11, R12, R13: 49k9; R_0603_1608Metric
SW1, SW2: SW_Push; SW_Push_1P1T_NO_6x6mm_H9.5mm
SW3: SW_DIP_x01; SW_DIP_SPSTx01_Slide_9.78x4.72mm_W7.62mm_P2.54mm
U1: CH340X; MSOP-10_3x3mm_P0.5mm

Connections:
+3V3: C5.1, J2.6, J5.4 (VDD), J6.1, R8.1, R9.1, R10.1, R11.1, R12.1, R13.1, SW2.2
/BOOT0: J1.7, SW2.1, U1.6 (TNOW)
/I2C_SCL: J1.3, J6.3
/I2C_SDA: J1.5, J6.2
/PA0: J2.7, J5.9 (DET)
/PA1: J2.5, SW3.1
/SPI_MISO: J1.6, J5.7 (DAT0), R12.2
/SPI_MOSI: J1.8, J5.3 (CMD), R10.2
/SPI_SCK: J1.4, J5.5 (CLK), R11.2
/SPI_nCS: J1.2, J5.2 (DAT3/CD), R9.2
/UART_RX: J2.1, U1.8 (TXD)
/UART_TX: J2.3, U1.9 (RXD)
/VOUT: C4.2, J2.2
/nRESET: J1.1, R1.2, SW1.1
GND: C1.2, C2.2, C3.2, C5.2, J2.4, J3.A1 (GND), J3.A12 (GND), J3.B1 (GND), J3.B12 (GND), J3.S1 (SHIELD), J5.6 (VSS), J5.10 (SHIELD), J6.4, J7.S, R2.2, R3.2, R6.1, R7.1, SW1.2, SW3.2, U1.3 (GND)
unnamed: C2.1, FB1.1, J3.A4 (VBUS), J3.A9 (VBUS), J3.B4 (VBUS), J3.B9 (VBUS)
unnamed: C4.1, R5.2
unnamed: J3.A5 (CC1), R2.1
unnamed: J3.B5 (CC2), R3.1
unnamed: J5.8 (DAT1), R13.2
unnamed: J5.1 (DAT2), R8.2
unnamed: J7.T, R4.1, R6.2, R7.2
unnamed: R4.2, R5.1
unnamed: J3.A6 (D+), J3.B6 (D+), U1.1 (UD+)
unnamed: J3.A7 (D-), J3.B7 (D-), U1.2 (UD-)
unnamed: C1.1, U1.10 (V3)
unnamed: R1.1, U1.4 (~RTS)
VCC: C3.1, FB1.2, J2.8, U1.7 (VCC)

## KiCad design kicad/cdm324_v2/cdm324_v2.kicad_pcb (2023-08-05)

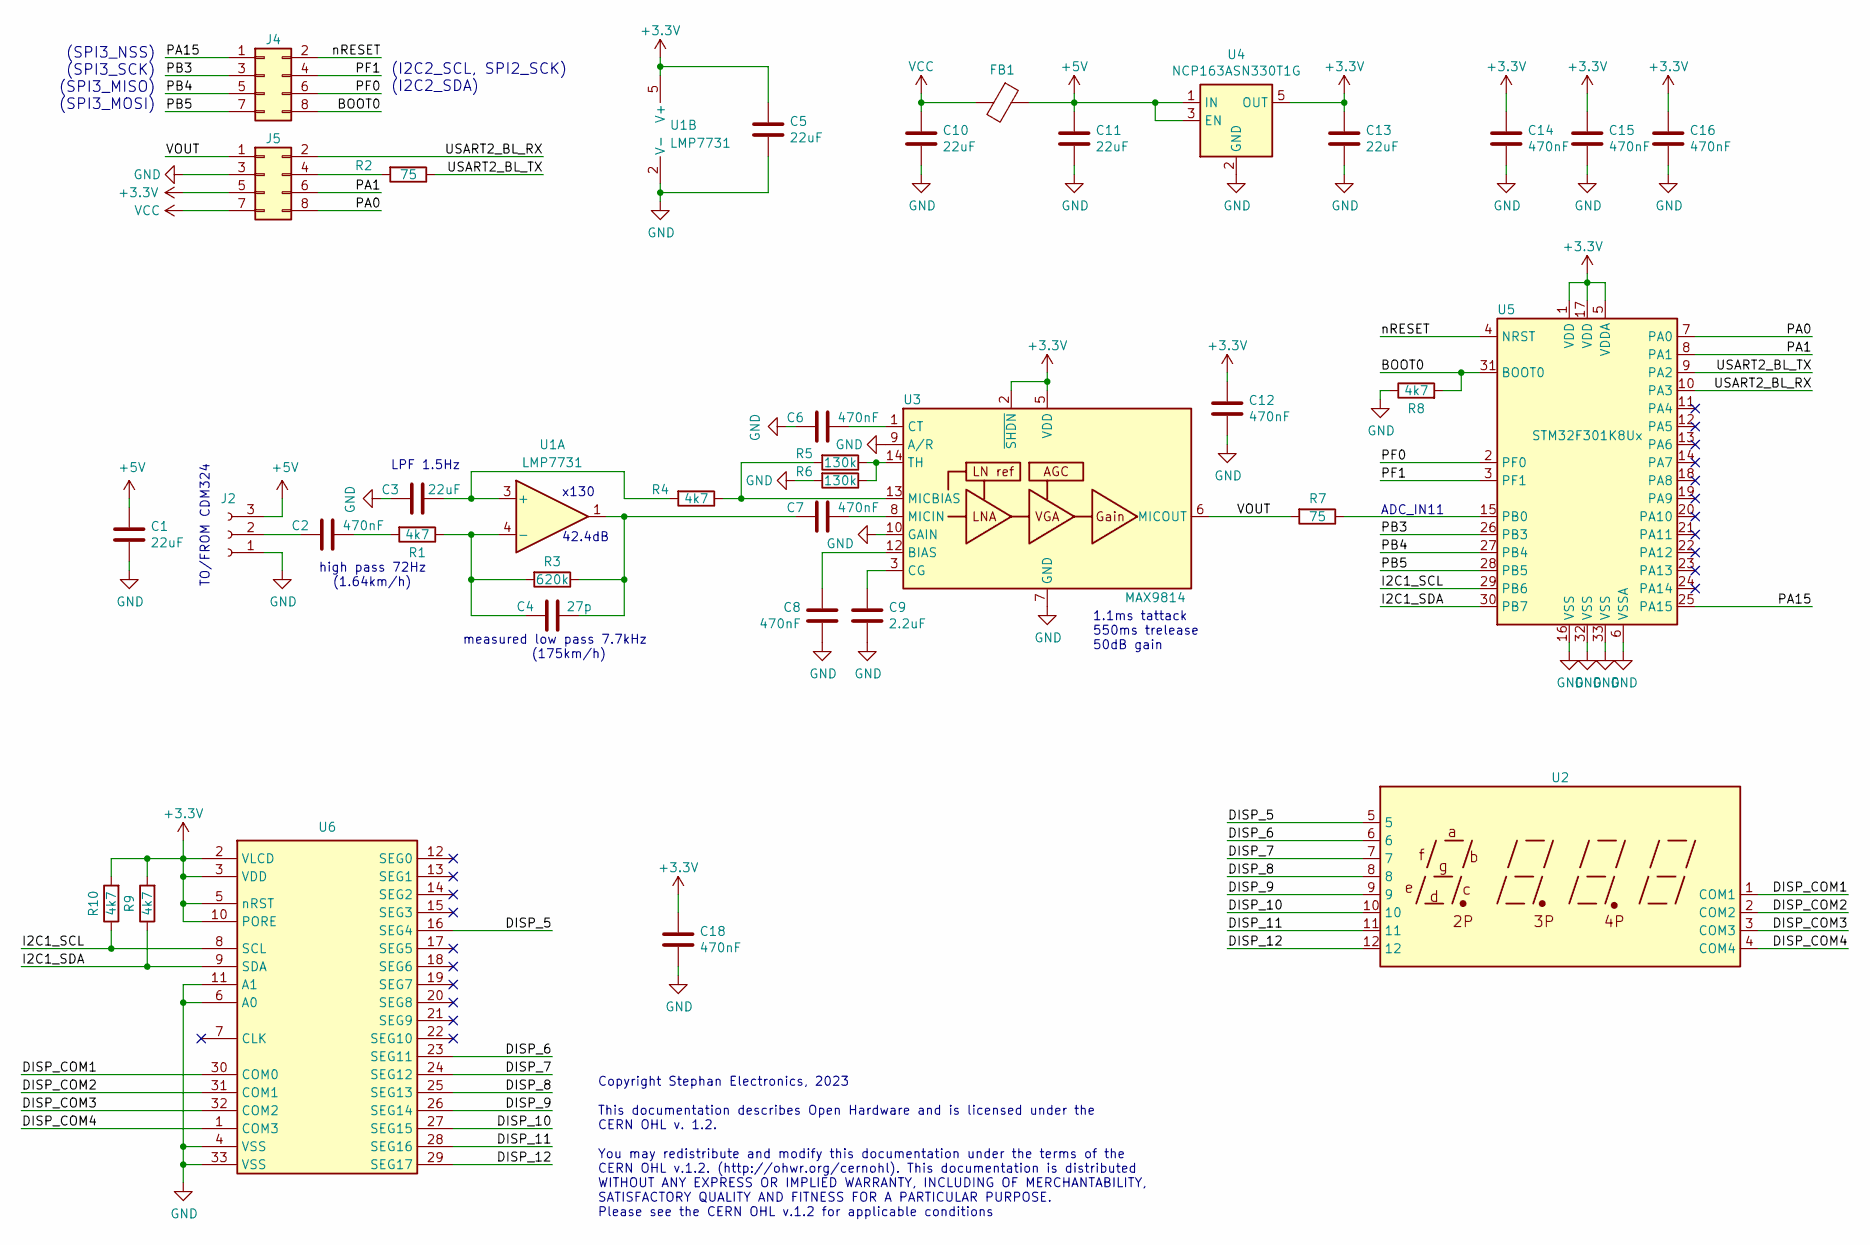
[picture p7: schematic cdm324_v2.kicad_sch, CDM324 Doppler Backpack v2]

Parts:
C1, C3, C5, C10, C11, C13: 22uF; C_0805_2012Metric
C2, C6, C7, C8, C12, C14, C15, C16, C18: 470nF; C_0402_1005Metric
C4: 27p; C_0603_1608Metric
C9: 2.2uF; C_0603_1608Metric
FB1: Ferrite_Bead; L_0805_2012Metric
J2: Conn_01x03_Female; PinHeader_1x03_P2.54mm_Vertical
J4, J5: Conn_02x04_Odd_Even; PinSocket_2x04_P2.54mm_Vertical
R1, R4, R8, R9, R10: 4k7; R_0603_1608Metric
R2, R7: 75; R_0402_1005Metric
R3: 620k; R_0603_1608Metric
R5, R6: 130k; R_0603_1608Metric
U1: LMP7731; SOT-23-5
U2: TN_DISPLAY
U3: MAX9814; DFN-14-1EP_3x3mm_P0.4mm_EP1.78x2.35mm
U4: NCP163ASN330T1G; SOT-23-5
U5: STM32F301K8Ux; QFN-32-1EP_5x5mm_P0.5mm_EP3.45x3.45mm
U6: QFN-32-1EP_5x5mm_P0.5mm_EP3.65x3.65mm

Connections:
+3V3: C5.1, C12.1, C13.1, C14.1, C15.1, C16.1, C18.1, J5.5, R9.2, R10.2, U1.5 (V+), U3.2 (~SHDN), U3.5 (VDD), U4.5 (OUT), U5.1 (VDD), U5.5 (VDDA), U5.17 (VDD), U6.2 (VLCD), U6.3 (VDD), U6.5 (nRST), U6.10 (PORE)
+5V: C1.1, C11.1, FB1.1, J2.3, U4.1 (IN), U4.3 (EN)
/BOOT0: J4.8, R8.2, U5.31 (BOOT0)
/DISP_5: U2.5, U6.16 (SEG4)
/DISP_6: U2.6, U6.23 (SEG11)
/DISP_7: U2.7, U6.24 (SEG12)
/DISP_8: U2.8, U6.25 (SEG13)
/DISP_9: U2.9, U6.26 (SEG14)
/DISP_10: U2.10, U6.27 (SEG15)
/DISP_11: U2.11, U6.28 (SEG16)
/DISP_12: U2.12, U6.29 (SEG17)
/DISP_COM1: U2.1 (COM1), U6.30 (COM0)
/DISP_COM2: U2.2 (COM2), U6.31 (COM1)
/DISP_COM3: U2.3 (COM3), U6.32 (COM2)
/DISP_COM4: U2.4 (COM4), U6.1 (COM3)
/I2C1_SCL: R10.1, U5.29 (PB6), U6.8 (SCL)
/I2C1_SDA: R9.1, U5.30 (PB7), U6.9 (SDA)
/PA0: J5.8, U5.7 (PA0)
/PA1: J5.6, U5.8 (PA1)
/PA15: J4.1, U5.25 (PA15)
/PB3: J4.3, U5.26 (PB3)
/PB4: J4.5, U5.27 (PB4)
/PB5: J4.7, U5.28 (PB5)
/PF0: J4.6, U5.2 (PF0)
/PF1: J4.4, U5.3 (PF1)
/USART2_BL_RX: J5.2, U5.10 (PA3)
/USART2_BL_TX: R2.1, U5.9 (PA2)
/VOUT: J5.1, R7.2, U3.6 (MICOUT)
/nRESET: J4.2, U5.4 (NRST)
GND: C1.2, C3.2, C5.2, C6.2, C8.2, C9.2, C10.2, C11.2, C12.2, C13.2, C14.2, C15.2, C16.2, C18.2, J2.1, J5.3, R6.2, R8.1, U1.2 (V-), U3.4 (GND), U3.7 (GND), U3.9 (A/R), U3.10 (GAIN), U3.11 (GND), U3.15 (GND), U4.2 (GND), U5.6 (VSSA), U5.16 (VSS), U5.32 (VSS), U5.33 (VSS), U6.4 (VSS), U6.6 (A0), U6.11 (A1), U6.33 (VSS)
unnamed: C2.1, R1.2
unnamed: C4.1, C7.2, R3.1, U1.1
unnamed: C2.2, J2.2
unnamed: J5.4, R2.2
unnamed: C3.1, R4.2, U1.3 (+)
unnamed: C4.2, R1.1, R3.2, U1.4 (-)
unnamed: C8.1, U3.12 (BIAS)
unnamed: C9.1, U3.3 (CG)
unnamed: C6.1, U3.1 (CT)
unnamed: R4.1, R5.2, U3.13 (MICBIAS)
unnamed: C7.1, U3.8 (MICIN)
unnamed: R5.1, R6.1, U3.14 (TH)
unnamed: R7.1, U5.15 (PB0)
VCC: C10.1, FB1.2, J5.7

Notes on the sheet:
1.1ms tattack 550ms trelease 50dB gain
measured low pass 7.7kHz (175km/h)
(SPI3_NSS) (SPI3_SCK) (SPI3_MISO) (SPI3_MOSI)
TO/FROM CDM324
Copyright Stephan Electronics, 2023 This documentation describes Open Hardware and is licensed under the CERN OHL v. 1.2. You may redistribute and modify this documentation under the terms of the CERN OHL v.1.2. (http://ohwr.org/cernohl). This documentation is distributed WITHOUT ANY EXPRESS OR IMP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
ADC_IN11
x130
high pass 72Hz (1.64km/h)
LPF 1.5Hz
42.4dB
(I2C2_SCL, SPI2_SCK) (I2C2_SDA)

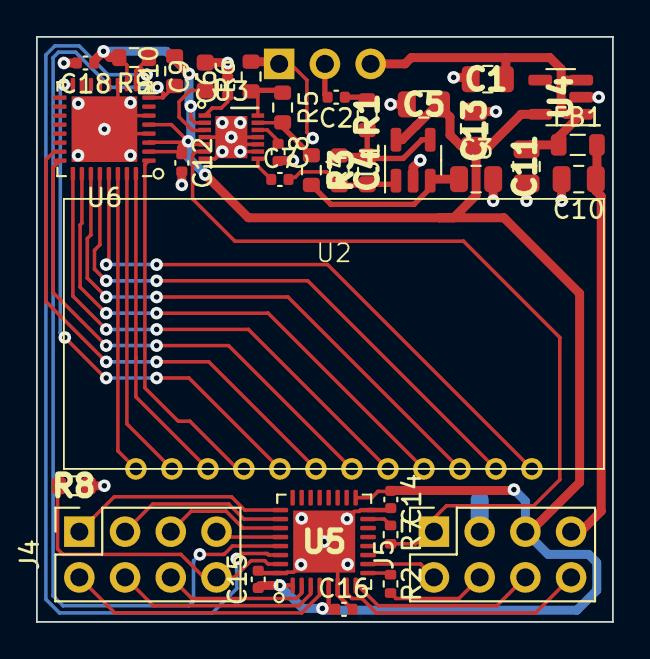
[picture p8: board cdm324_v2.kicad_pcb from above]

Board: 2 copper layers, 32.0 x 32.5 mm, 37 parts (1 on the bottom side), 44 nets.

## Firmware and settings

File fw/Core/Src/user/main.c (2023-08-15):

#include "user/expander_board.h"
#include "user/display.h"
#include "user/defines.h"
#include "user/analog.h"
#include "user/clocks.h"
#include "user/debug.h"
#include "user/main.h"
// Do we skip data analysis after updating display?
//#define SKIP_ADC_DATA_AFTER_DISPLAY
// After how many FFTs do we update display
#define FFT_CNT_DISP 10
// Define to enable current transient test
//#define CUR_TRANSIENT_TEST


/*! \fn     main_user(void)
*   \brief  User main
*/
void main_user(void)
{
	BOOL output_debug_enabled = FALSE;
	BOOL sd_card_initialized = FALSE;
	BOOL remove_low_freqs = FALSE;
	uint16_t last_fft_return = 0;
	uint16_t fft_nb_counter = 0;
	uint16_t idle_anim_st = 0;
#ifdef CUR_TRANSIENT_TEST
	uint16_t temp_counter = 0;
#endif

	/* Clock init */
	clocks_init();

	/* Debug init */
	debug_init();

	/* Say hello! */
	debug_printf("CDM324 fw v%d.%d, compiled %s %s\r\n", FW_MAJOR, FW_MINOR, __DATE__, __TIME__);

	/* Display init */
	if (display_init() == FALSE)
	{
		debug_print_string("Display not found!\r\n");
		while(1);
	}

	/* Analog input init */
	analog_init();

	/* IO expander init */
	if (expander_init() != FALSE)
	{
		sd_card_initialized = TRUE;
	}

	/* Trigger analog conversions */
	analog_trigger_conversion();

	while (1)
	{
		/* Sequence of ADC measurements complete? */
		if(analog_get_and_clear_adc_measurement_done() != FALSE)
		{
			/* Every few ms we display the speed and depending on define not do anything with the data has the current draw is enough to have an impact on the +5V PSU */
			if (fft_nb_counter++ == FFT_CNT_DISP)
			{
				/* Reset counter */
				fft_nb_counter = 0;
			}
#ifdef SKIP_ADC_DATA_AFTER_DISPLAY
			else
#endif
			{
				/* Should we display the result? */
				if (fft_nb_counter == FFT_CNT_DISP)
				{
#ifndef CUR_TRANSIENT_TEST
					/* Valid return? */
					if (last_fft_return == 0)
					{
						/* Idle animation */
						display_animation_step(idle_anim_st++);
						if (idle_anim_st == 12)
						{
							idle_anim_st = 0;
						}
					}
					else
					{
						/* Convert to mph or kph depending on user selection */
						if (expander_is_kph_selected() != FALSE)
						{
							display_speed((uint16_t)(last_fft_return * 0.2262295));
						}
						else
						{
							display_speed((uint16_t)(last_fft_return * 0.1449275));
						}
					}
#else
					/* Code to test current transient */
					if ((temp_counter++ & 0x0001) == 0)
						display_text("", FALSE);
					else
						display_speed(8888);
#endif
				}

				/* Debug ADC output buffer ? */
				if(output_debug_enabled != FALSE)
				{
					analog_output_conversion_buffer_to_uart();
				}

				/* Compute FFT */
				last_fft_return = analog_compute_fft_on_cplted_sequence(remove_low_freqs);

				/* Debug FFT output buffer ? */
				if(output_debug_enabled != FALSE)
				{
					analog_output_current_fft_to_uart(150);
				}

				/* Commands from UART */
				char uart_input = debug_get_char_from_uart();
				if(uart_input == 'a')
				{
					output_debug_enabled = TRUE;
				}
				else if(uart_input == 's')
				{
					output_debug_enabled = FALSE;
				}
				else if(uart_input == 'h')
				{
					remove_low_freqs = TRUE;
				}
				else if(uart_input == 'l')
				{
					remove_low_freqs = FALSE;
				}
				else if(uart_input == 'k')
				{
					debug_printf("%d\r\n", (uint16_t)(last_fft_return * 0.2262295));
				}
				else if(uart_input == 'm')
				{
					debug_printf("%d\r\n", (uint16_t)(last_fft_return * 0.1449275));
				}
			}
		}

	}
}

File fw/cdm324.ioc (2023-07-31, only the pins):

Mcu.UserName=STM32F301K8Ux
PA0.Signal=GPIO_Input
PA1.Signal=GPIO_Input
PA15.Signal=GPIO_Output
PA2.Signal=USART2_TX
PA3.Signal=USART2_RX
PB0.GPIO_Label=DOPPLER
PB0.Signal=ADC1_IN11
PB3.Signal=SPI3_SCK
PB4.Signal=SPI3_MISO
PB5.Signal=SPI3_MOSI
PB6.Signal=I2C1_SCL
PB7.Signal=I2C1_SDA

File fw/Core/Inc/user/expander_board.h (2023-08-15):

#ifndef EXPANDER_H_
#define EXPANDER_H_

#include "stm32f3xx_hal.h"
#include "user/defines.h"

/* Defines */
#define SD_CD_Pin 			GPIO_PIN_0
#define SD_CD_Pin_Port 		GPIOA
#define SWITCH_Pin 			GPIO_PIN_1
#define SWITCH_GPIO_Port 	GPIOA
#define SPI_SS_Pin 			GPIO_PIN_15
#define SPI_SS_GPIO_Port 	GPIOA
#define SD_CS_Pin 			SPI_SS_Pin
#define SD_CS_GPIO_Port 	SPI_SS_GPIO_Port

/* Prototypes */
BOOL expander_is_kph_selected(void);
BOOL expander_init(void);

#endif

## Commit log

2023-08-05 first stage changed, POR for segment controller
    [cdm324_exp.kicad_pcb, cdm324_v2.kicad_pcb, cdm324_v2.kicad_sch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]
2023-08-08 correct resistor divider for jack output
    [cdm324_exp-B_Fab.gbr, cdm324_exp-F_Fab.gbr, cdm324_exp.drl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]
2023-08-15 kmh/mph switch, sd card writing tested
2023-10-15 explansion board schematics in pdf format
2023-10-29 sample arduino code
2024-08-21 3D printed plastic holder file upload, fix #13
    [holder.stl]
